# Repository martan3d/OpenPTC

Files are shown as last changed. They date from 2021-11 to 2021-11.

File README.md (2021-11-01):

# OpenPTC
Open Source Protothrottle Compatible Controller

This is a simple, Protothrottle Compatible Transmitter that I have been working on.  It should work with any of the default base stations,  but I have only tested it with my own deadrail receiver.  

For now, it is a work in progress. I am planning on a simple python/windows app to program the function codes for each button and switch, but at the moment it is hardcoded, although easy to change.  

The code is all C, no Arduino Libraries are used but it is fairly simple.  There are five possible Locomotive Storage 'slots', on the faceplate there is an LED indicator for each.  There are three large buttons, I typically set these to Function codes for the Brake (red) Aux (blue) and Horn (yellow).  There are four programmable switches on the bottom, I generally set these to bell, lights, ditch lights and engine start/stop but these are just my personal defaults, you can set any of the buttons or switches to any function code you like.  The settings are stored in EEPROM and the code is setup to send and receive the configuration messages via Xbee Directed messages, however at this point I have not tested them.

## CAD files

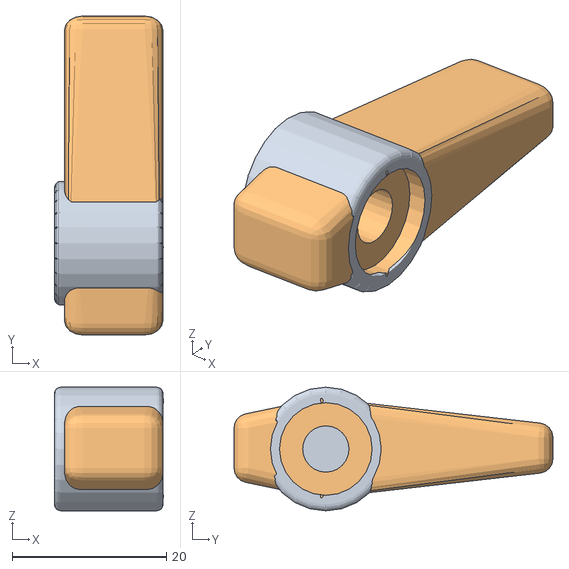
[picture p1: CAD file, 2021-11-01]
3DParts/knobCutHole.stl
14.1 x 41.3 x 16.0
Form10
Form13

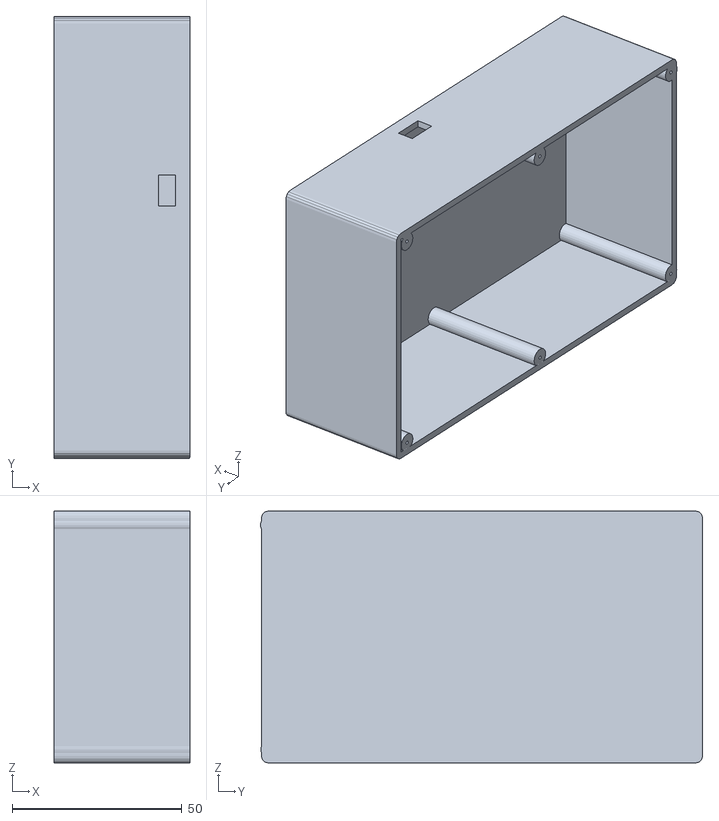
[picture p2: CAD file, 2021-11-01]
3DParts/CaseWSwitch.stl
40.0 x 130.1 x 74.1

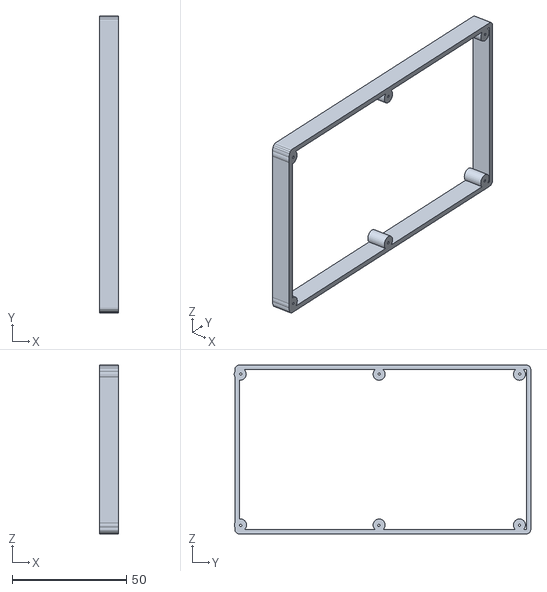
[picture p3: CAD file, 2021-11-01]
3DParts/CaseExtension.stl
8.25 x 130.1 x 74.1

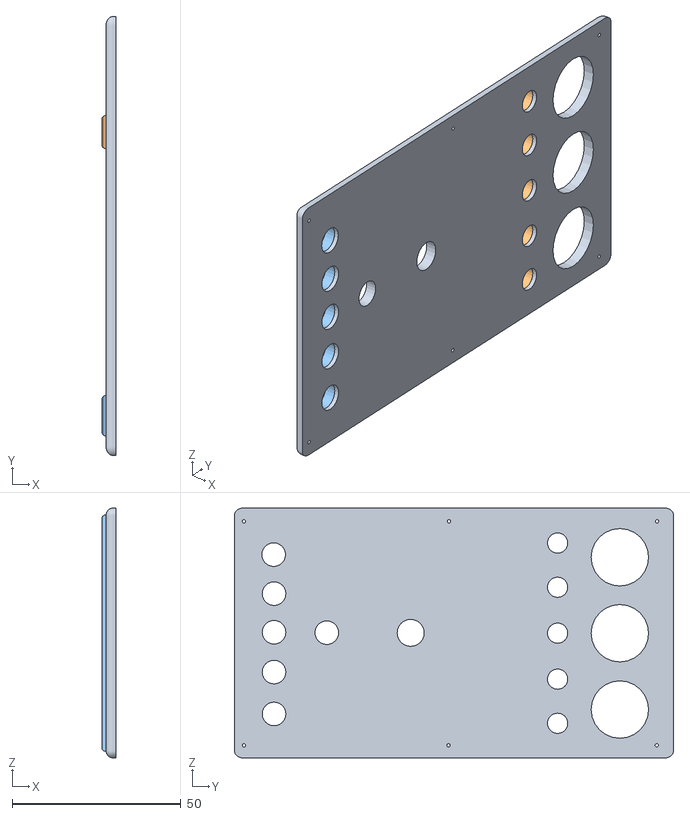
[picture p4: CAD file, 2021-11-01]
3DParts/faceplate.stl
4.24 x 130.0 x 74.0
Form119
Form122
Form125

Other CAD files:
3DParts/Case.stl

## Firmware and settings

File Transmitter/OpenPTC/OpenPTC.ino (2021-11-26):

#include <avr/io.h>
#include <avr/interrupt.h>

/*  Protothrottle Clone 
 *   
 * This is the format of the PT packet sent out every 1000ms if nothing changes.  If there is a change, it's sent immediately
 * 
 *  Byte0    = Address of the base/receiver.  0xD0 to 0xEF.  The PT displays 0 to 31 for simplicity, but internally adds 0xD0 to the value.
 *  Byte1    = Address of the ProtoThrottle.  0x30 to 0x49.  The PT displays A to Z for simplicity, but internally translates to 0x30 to 0x49.
 *  Byte2    = 15 (packet size)
 *  Byte3,4  = CRC16 for data validation
 *  Byte5    = 'S' for Status Packet
 *  Byte 6,7 = 16-bit locomotive address.  Long address (0-9999) if MSB clear.  Short address (0-127) if MSB set.
 *  Byte 8   = Speed/direction.  Encoded the same as DCC "128 step" mode.  0 = idle, 1 = e-stop, 2-127 = speed, MSB = direction
 *  Byte 9   = Functions 28-24
 *  Byte 10  = Functions 23-16
 *  Byte 11  = Functions 15-8
 *  Byte 12  = Functions 7-0
 *  Byte 13  = Status bits.  Currently only supports emergency stop.
 *  Byte 14  = Battery voltage (20mV per LSB)
 *
 ******************************************************************
 *
 *  PROMINI PINS in order, in groups of three.  The software DEPENDS on these
 *  being in the correct order. Optional ISP hookup, two groups of three.
 *  (ISP is only needed if you 'brick' the bootloader on the ProMini)
 *
 *  TX   Xbee DIN                        RAW
 *  RX   XBee OUT                        GND                -----
 *  RST                                  RST                    |
 *                                                              |    ISP 0
 *  GND                                  VCC                -----
 *  PD2  SW4 Sel button                  PC3 LED 0
 *  PD3  SW3                             PC2 LED 1
 *  
 *  PD4  SW2                             PC1 LED 2
 *  PD5  SW1                             PC0 ADC Input
 *  PD6  SW0                             PB5 LED 3          -----
 *                                                              |
 *  PD7  BUTTON YELLOW                   PB4 LED 4              |    ISP 1
 *  PB0  BUTTON AUX (GREEN? blue)        PB3 LED STOP       -----
 *  PB1  BUTTON RED                      PB2 Dir Switch
 *
 *
 */

#include "adc.h"
#include "xbee.h"
#include "timer.h"
#include "buttons.h"
#include "eedata.h"
#include "functions.h"
#include "message.h"

/*******************************************************************/

uint8_t  txdata[]  = {0xD0, 0x30, 0x0F, 0x6F, 0x93, 0x53, 0x08, 0x34, 0x80, 0x00, 0x00, 0x00, 0x00, 0x00, 0x88};
uint16_t address   = 2606;
uint8_t  dir       = 0;

uint16_t adcValue  = 0;
uint32_t now       = 0;
uint32_t then      = 0;
uint8_t  updatenow = 0;

uint32_t nowbutton  = 0;
uint32_t thenbutton = 0;


uint8_t  BData = 0;
uint8_t  CData = 0;
uint8_t  DData = 0;
uint8_t  adc   = 0;
uint8_t  adcOld = 0;

uint8_t BDataOld = 0;
uint8_t DDataOld = 0;

uint8_t *p;

#define MAXTIME 1000
#define BUTTONTIME 200
#define PMLED   0x20

uint16_t maxtime = MAXTIME;
uint8_t  masterIndex = 0;
uint8_t  oldIndex = 0;
uint8_t  select = 0;

int main(void)
{
  
  initSerial(38400);            // run Xbee at 34.8K baud
  initTimer();                  // Setup the millisecond timer
  initADC();                    // Startup the ADC irq
  initButtons();                // set IO ports
  
//hard code init of EEPROM
//defaultFunctionCodes();
//defaultLocoAddresses();
///////

  readAllGroupDataFromEEPROM();               // load sram loco groups from EEPROM
  readAllLocoAddressesFromEEPROM();           // load PT loco addresses from EEPROM
  
  address = getLocoAddress(masterIndex);      // grab the default transmit address
  txdata[6] = address >> 8;                   // xbee loco address returned in PT packet
  txdata[7] = address & 0x00ff;               // this is the address the receiver responds to  

  outputLEDS(masterIndex);                    // turn on the proper loco indicator LEDs 1-5

  sei();                                      // start the engines - enable interrupts

  enableRXIRQ();
        
  then = getMsClock();                        // get initial clock reading for the transmit times
  thenbutton = getMsClock();                  // for the button check too
  
  while(1)
  {
        /* collect buttons and knob data, process and load data packet for PT broadcast */

        adc = (getADC()/8) & 0x7f;            // ADC runs on irq, get Knob value and adjust to 0-127
    
        scanButtons();                        // Process input data for buttons/switches

        BData = getBData();                   // return debounced data for each port
        DData = getDData();

        updatenow = BData ^ BDataOld;         // has anything changed from the last scan?
        updatenow |= DData ^ DDataOld;        // if so, we need to send a packet now
        updatenow |= (adc&0xfc) ^ (adcOld&0xfc);

        BDataOld = BData;                     // save for next scan in a few microseconds
        DDataOld = DData;
        adcOld   = adc;

        dir = ( (BData & DIRECTION) << 5);    // get the direction switch data and move it to bit 7

        p = processInputs( masterIndex, BData, DData);  // process the inputs into programmed function codes

        txdata[8]  = adc | dir;               // insert direction bit into adjusted throttle value
        txdata[9]  = p[3];                    // insert adjusted button readings into the PT broadcast packet
        txdata[10] = p[2];                    // for all of the function code possibilities
        txdata[11] = p[1];                    // see PT packet format above
        txdata[12] = p[0];

        txdata[13] = BData;
        txdata[14] = DData;

        /* check to see if user has switched to a new locomotive */

        nowbutton = getMsClock();
        if ((nowbutton - thenbutton) > BUTTONTIME)
        {
            thenbutton = getMsClock();        // grab for next pass

            if( (DData & SELECTBUTTON) )      // Advance Loco Number (more later, need off/on/sleep)
              {
                masterIndex++;                // it was pressed, advance to next locomotive
                if (masterIndex > 4)
                    masterIndex = 0;
              }
        }

        /* if we have a new loco selected, reload the data and set the LEDS */
        
        if (oldIndex != masterIndex)           // only need to do this if masterIndex changes
        {                                      // no need to reload data unless we have to
           oldIndex = masterIndex;             // it changed, save for next pass
           
           address = getLocoAddress(masterIndex);
           txdata[6] = address >> 8;           // xbee loco address
           txdata[7] = address & 0x00ff;       // goes into the PT transmit packet

           outputLEDS(masterIndex);            // New loco- turn on the proper loco indicator LEDs
        }

        /* Send out Xbee PT packet data every second if nothing else going on */
        
        now = getMsClock();                    // time to send data?
        if ((now - then) > maxtime)
        {
            then = getMsClock();              // time to send, grab this for next time, maxtime from now
              
            if (!transmitting())              // if we are in the middle of a transmission, don't try another, wait
            {
                //xbeeTransmitPTFrame(0xff, 0xff, txdata);
            }
            else
              updatenow = 1;                 // make sure it goes out right now or next pass if it can
        }

        /* if any data has changed since last pass, send it now */
        if (updatenow)
        {
            if (!transmitting()){
                xbeeTransmitPTFrame(0xff, 0xff, txdata);
                then = getMsClock();
                updatenow = 0;
            }
        }

        if (msgRX() != 0)                      // Xbee directed message come in?
        {
           processDirectedMessage();           // process it
           clrmsgRX();
           then = getMsClock();                // reset timer to allow directed transactions
        }
  }
}

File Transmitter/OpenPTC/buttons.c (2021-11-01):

/*
 * buttons.c
 *
 * Created: 9/14/2013 9:31:58 AM
 * Author: martan
 */

#include <avr/io.h>
#include "buttons.h"

// debounce filters

int8_t BFilter[3];
int8_t DFilter[6];

// working data

uint8_t Binputs = 0;
uint8_t Dinputs = 0;

// debounced data

uint8_t Bdata = 0;
uint8_t Ddata = 0;

/* init I/O ports 
 *  
 *   0 = input pin, 
 *   1 = output pin
 * 
 * 
 */

uint8_t leds[5] = { LED0, LED1, LED2, LED3, LED4, LEDSTOP };

#define BOUNCE 8

void initButtons()
{
  DDRD   = 0x01;                                                                 // D0 = Tx output to Xbee, D1 = Rx
  DDRD  &= ~(SELECTBUTTON | SWITCH0 | SWITCH1 | SWITCH2 | SWITCH3 | BUTTON2);    // inputs = 0
  PORTD |=  (SELECTBUTTON | SWITCH0 | SWITCH1 | SWITCH2 | SWITCH3 | BUTTON2);    // turn on internal pullups (important)
                                
  DDRB   =  (LED3 | LED4 | LEDSTOP);                                             // all inputs except these
  PORTB |=  (BUTTON0 | BUTTON1 | DIRECTION | LED3 | LED4 | LEDSTOP);             // Pullups for buttons and direction switch, turn off LEDS

  DDRC    = ~ADC;                          // PC0 = ADC input, not really needed, config of ADC takes preference all others outputs
  PORTC  |= (~ADC | LED0 | LED1 | LED2);   // outputs to 1 turns OFF leds

  BFilter[0] = BFilter[1] = BFilter[2] = 0;
  DFilter[0] = DFilter[1] = DFilter[2] = DFilter[3] = DFilter[4] =  DFilter[5] = 0;
}

/*
 * Return our processed (debounced) data values for all buttons and switches 
 * 
 */

uint8_t getBData()
{
   return Bdata;
}

uint8_t getDData()
{
   return Ddata;
}

/*
 * Debounce Input Buttons - Pointer magic
 *
 */

uint8_t filterInput(uint8_t inputs, uint8_t button, int8_t *filter)
{
    uint8_t rdata = 0;

    if(inputs & button)          // Passed in button input
      (*filter)++;
    else
      (*filter)--;

    if( *filter > BOUNCE)        // Must see one this many scans ON
    {
      rdata |= button;           // to be ON (1)
      *filter = BOUNCE;
    }
    
    if( *filter < 1)             // or zero this many scans
    {
      rdata &= ~(button);        // to be zero
      *filter = 0;
    }

  return rdata;
}
    
   
/*
 * Grab button states from the ports, zero means pressed, so invert them 
 *
 */

 
void scanButtons()
{
    /****** PORTB input pins ******/

    Binputs = PINB;              // get all input data
    Binputs = ~Binputs;          // invert bits, 0 means ON, change to 1 = ON

    Bdata = 0;
    Bdata |= filterInput(Binputs, BUTTON0, &BFilter[0]);
    Bdata |= filterInput(Binputs, BUTTON1, &BFilter[1]);
    Bdata |= filterInput(Binputs, DIRECTION, &BFilter[2]);
    
    /********* PORTD input pins **********/

    Dinputs = PIND;              // get all input data
    Dinputs = ~Dinputs;          // invert bits, 0 means ON, change to 1 = ON

    Ddata = 0;
    Ddata |= filterInput(Dinputs, SELECTBUTTON, &DFilter[0]);
    Ddata |= filterInput(Dinputs, SWITCH0, &DFilter[1]);
    Ddata |= filterInput(Dinputs, SWITCH1, &DFilter[2]);
    Ddata |= filterInput(Dinputs, SWITCH2, &DFilter[3]);
    Ddata |= filterInput(Dinputs, SWITCH3, &DFilter[4]);
    Ddata |= filterInput(Dinputs, BUTTON2, &DFilter[5]);

}
  

/* turn on 'index' LED from 0-4 (Actually sets the port to 'low') */

void outputLEDS(uint8_t index)
{
       switch(index)
       {
          case 0:
          case 1:
          case 2:
                  PORTC = (LED0 | LED1 | LED2);
                  PORTB = (LED3 | LED4 | LEDSTOP);
                  PORTC &= ~leds[index];
                  break;
          case 3:
          case 4:
                  PORTC = (LED0 | LED1 | LED2);
                  PORTB = (LED3 | LED4 | LEDSTOP);
                  PORTB &= ~leds[index];
                  break;
       }
}

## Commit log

2021-10-03 move things, add 3d folder
    [faceplate.stl]
2021-10-05 base working ADC/Xbee
2021-10-16 add completed box and faceplate
    [FinalBoxAndFacePlate02.stl]
2021-10-17 fix eemem pointers, add function code lookup
    [OpenPTC.ino, buttons.c]
2021-10-18 wrong place in PT packet, added msglen to xbee datagram
    [OpenPTC.ino, buttons.c]
2021-10-24 revise EEPROM - EEMEM doesn't work right, use defined offsets
    [OpenPTC.ino, adc.c, buttons.c]
2021-11-01 Latest Revisions - Case complete, everything fits
    [Case.stl, CaseExtension.stl, CaseWSwitch.stl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]
2021-11-01 update readme, delete old parts
    [FinalBoxAndFacePlate02.stl]
2021-11-01 add knob to 3DParts
    [knobCutHole.stl]
2021-11-24 add timer reset when background message is processed to prevent stomp on transmit
    [OpenPTC.ino]
2021-11-26 length bug in IRQ receiver code, see all RX code in all repos with variable xbee payloads
    [OpenPTC.ino]
